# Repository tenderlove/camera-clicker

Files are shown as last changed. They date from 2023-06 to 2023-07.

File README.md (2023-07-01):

# Camera Clicker

This project is a dedicated WiFi client and remote shutter for Olympus OM-D cameras.
It simply connects to the camera, and then you can use the button to fire the camera shutter.
I've only tested this with my OM-D E-M5 Mark III camera, but I believe it will work with any OM-D camera that uses WiFi for its remote shutter application.

<p align="center">
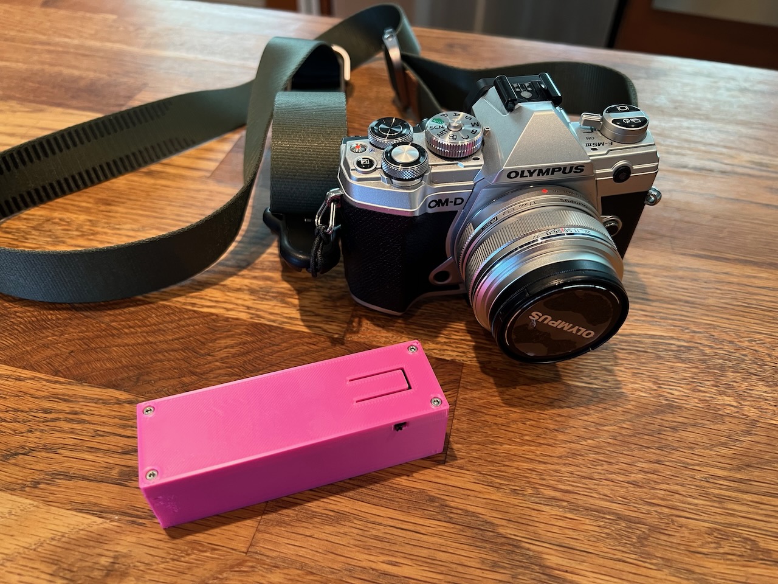
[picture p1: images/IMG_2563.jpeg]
  
</p>

In this repository, you'll find [schematics and PCB designs](pcb), [stl files](housing), and the [firmware](firmware) you need.

## Hardware

The hardware is based around the ESP32.  It uses an [LiFePO4 battery](https://www.digikey.com/en/products/detail/zeus-battery-products/PCIFR18650-1500/9828824) to provide power to the ESP32.
I chose this battery because it provides 3.2v which means I don't need a voltage regulator for the ESP32.
The schematic integrates a recharging circuit, so you can recharge the battery via USB C.

Below are the necessary parts:

| Quantity | Part | Value | Size |
| --- | ---- | ---- | ----- |
| 1 | [Battery Holder](https://www.digikey.com/en/products/detail/keystone-electronics/1042/2745668) |  | BatteryHolder_Keystone_1042_1x18650 |
| 1 | [Battery](https://www.digikey.com/en/products/detail/zeus-battery-products/PCIFR18650-1500/9828824) |  |  |
| 2 | Capacitor | 1uf | 0402 |
| 1 | Capacitor | 22uf | 1206 |
| 1 | Capacitor | 0.1uf | 1206 |
| 2 | LED |  | 1206 |
| 1 | [USB C connector](https://www.digikey.com/en/products/detail/amphenol-cs-fci/10164359-00011LF/18443702) |  | USB_C_Receptacle_Amphenol_10164359-3A |
| 1 | Resistor | 82k | 0402 |
| 1 | Resistor | 3k | 0402 |
| 4 | Resistor | 10k | 1206 |
| 1 | Resistor | 70k | 0402 |
| 1 | Resistor | 2.3k | 0402 |
| 2 | Resistor | 5.1k | 1206 |
| 1 | [Power Switch](https://www.digikey.com/en/products/detail/te-connectivity-alcoswitch-switches/1825232-1/4021554) |  |  |
| 2 | [Programming Switches](https://www.digikey.com/en/products/detail/c-k/PTS526-SK15-SMTR2-LFS/10056626) |  | SW_SPST_PTS526 |
| 1 | [Double Action Switch](https://www.digikey.com/en/products/detail/panasonic-electronic-components/EVP-AXBA1A/4930566) |  | EVPAX-A1A |
| 1 | NTC Thermistor | 10k NTC | 1206 |
| 1 | [Battery Charger](https://www.digikey.com/en/products/detail/texas-instruments/BQ25170DSGR/14124032) | BQ25170 | WSON-8-1EP_2x2mm_P0.5mm_EP0.9x1.6mm |
| 1 | [ESP32](https://www.digikey.com/en/products/detail/espressif-systems/ESP32-MINI-1-N4/13532111) |  |  |

You'll find the gerber files in the [pcb folder](pcb).
Also, I used 10k resistors for the LEDs, but I think it made the LEDs too dim, so maybe 1k is better.
The LEDs are used to indicate charging status, so I don't think they actually matter too much.

Here's a couple photos of the finished PCB:

<p align="center">
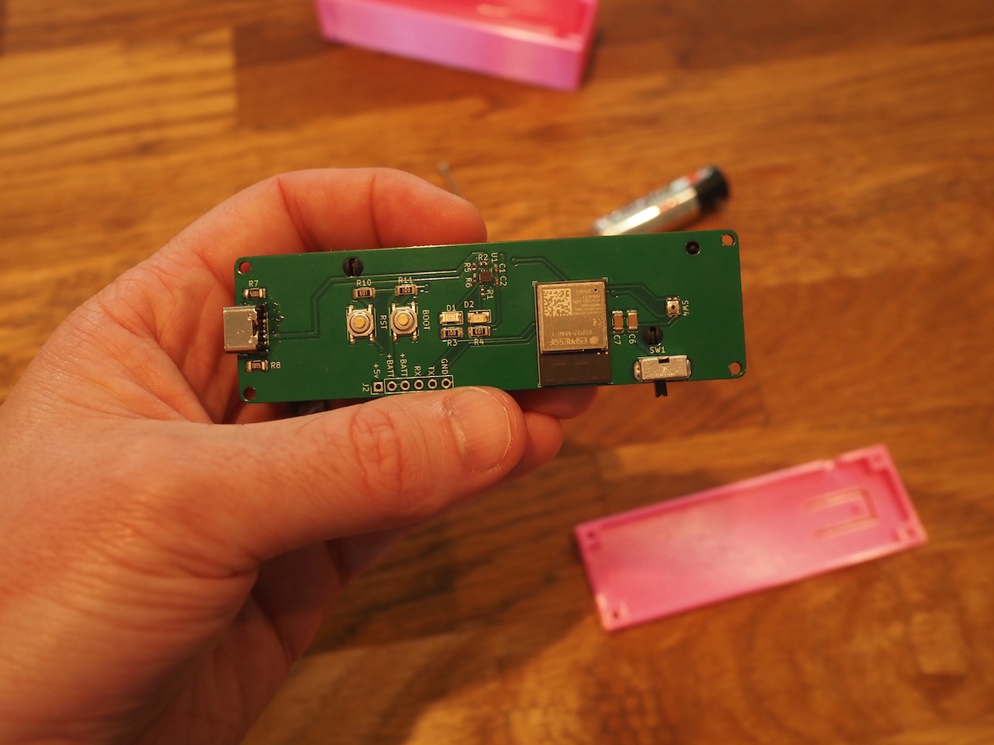
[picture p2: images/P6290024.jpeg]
PCB Top
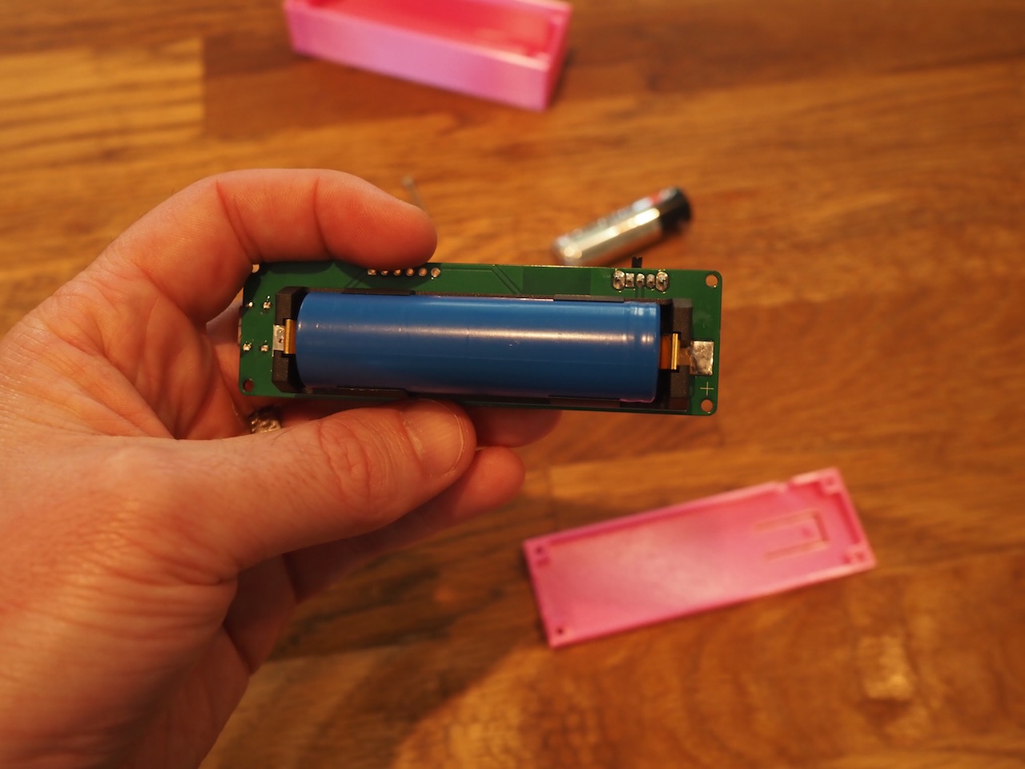
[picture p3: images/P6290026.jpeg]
PCB Bottom
   
</p>

## Firmware

The firmware is in the [firmware](firmware) folder.  It's a standard [ESP IDF](https://github.com/espressif/esp-idf) project.
In order to flash the ESP32, I used a [POGO Pin Clip](https://www.adafruit.com/product/5433) connected to a [USB to Serial](https://www.sparkfun.com/products/12731) board.

Once you have `esp-idf` installed, you can install the firmware like this:

```
$ idf.py build flash
```

Of course, make sure to press the BOOT and RST buttons to put the ESP32 in to programming mode.

## Housing

You can find STL files for the housing in the [housing](housing) folder.
Just print [`top.stl`](housing/top.stl) and [`bottom.stl`](housing/bottom.stl) and the PCB should fit inside.
The housing requires four M2 x 25mm bolts, and four 4mm hex nuts.

The PCB should fit in the housing like this:

<p align="center">
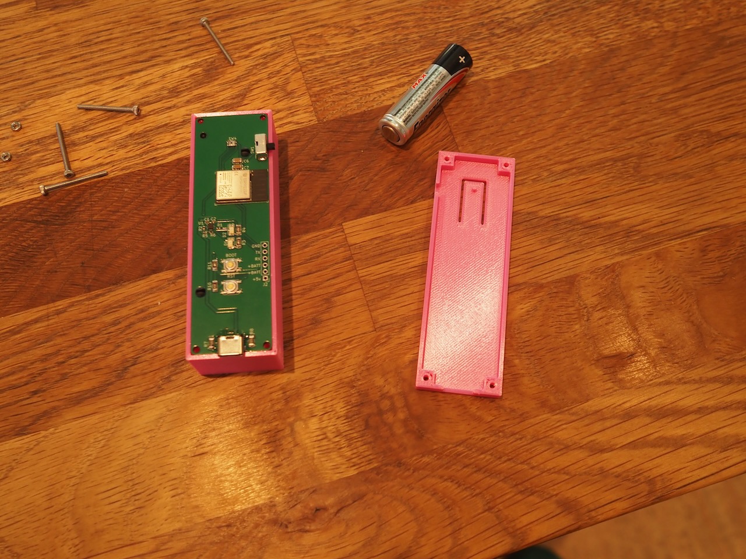
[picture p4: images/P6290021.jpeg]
  
</p>

## Using the Project

When you first turn the clicker on, it will create a WiFi hotspot with the SSID `CameraClicker` and the password `cameraclicker`.

My recommendation is to:

1. Turn on the camera, then enable WiFi client mode
2. Turn on the camera clicker
3. Connect to the camera clicker with your phone
4. Configure the camera clicker with the camera's WiFi settings (they will be displayed on the camera)
5. Use it!

The camera clicker will remember the camera's WiFi connection information, so you only need to configure it once.
If it can't connect to the camera for any reason, it will eventually start the WiFi hotspot again so that you can reconfigure it.

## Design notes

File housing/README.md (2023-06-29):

# Clicker Housing

The clicker housing is made of two parts and uses four M2 x 25mm bolts and four
4mm hex nuts.  Just print `top.stl` and `bottom.stl`.  The PCB should fit
inside!

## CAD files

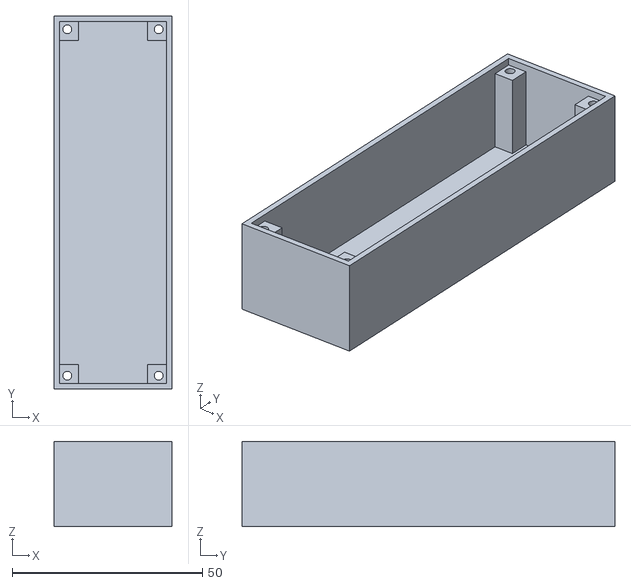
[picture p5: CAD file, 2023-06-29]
housing/bottom.stl
31.0 x 98.0 x 22.4

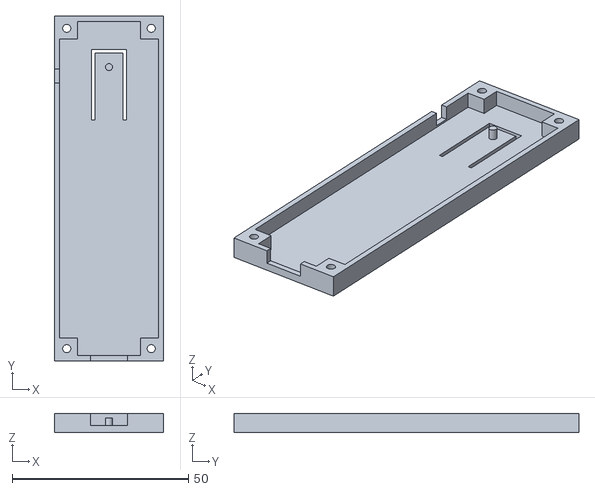
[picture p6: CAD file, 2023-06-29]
housing/top.stl
31.0 x 98.0 x 5.50

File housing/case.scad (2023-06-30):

W = 28;
D = 95;
H = 25;

PCB_W = W;
PCB_D = D;
PCB_H = 1.8;

BATTERY_W = 22;
BATTERY_D = 70;
BATTERY_H = 21 - PCB_H;

PCB_Z = BATTERY_H;

USB_W = 10.5;
USB_D = 5;
USB_H = 3.5;

POWER_SWITCH_W = 5;
POWER_SWITCH_D = 4;
POWER_SWITCH_H = 3.5;

CORNER_D = 5;
CORNER_W = 5;
WALL = 1.5;

PUSH_BUTTON_H = 1.3; // Increase this to make a larger gap above the button
PIN_DIAMETER = 1.1;
BOLT_DIAMETER = 2.3;

BOLT_HEAD_D = 4;
BOLT_HEAD_Z = 2.1;
NUT_D = 4.8;
NUT_Z = 3.1;

MOUNTING_HOLE_X = 24;
MOUNTING_HOLE_Y = 91;

module NegativeSpace() {
  difference() {
    translate([W / 2, D / 2, 0]) {
      translate([0, 0, H / 2])
        difference() {
          cube([W, D, H], center=true);

          // Corner Stands
          color("green")
            for (i = [-1, 1]) {
              for (j = [-1, 1]) {
                w = W - CORNER_W;
                d = D - CORNER_D;
                translate([(i * w / 2), (j * d / 2), 0])
                  cube([CORNER_W, CORNER_D, H + 1], center=true);
              }
            }
        }

      translate([0, 0, PCB_Z + (PCB_H / 2)])
        cube([W, D, PCB_H], center=true);

      // Screw holes
        for (i = [-1, 1]) {
          for (j = [-1, 1]) {
            w = MOUNTING_HOLE_X;
            d = MOUNTING_HOLE_Y;

            translate([(i * w / 2), (j * d / 2), BOLT_HEAD_Z + H - 0.5])
              rotate(180, [1, 0, 0])
              CounterSink(BOLT_HEAD_D, BOLT_HEAD_Z, BOLT_DIAMETER, facets=90);

            translate([(i * w / 2), (j * d / 2), -WALL - 0.1])
            CounterSink(NUT_D, NUT_Z, BOLT_DIAMETER, facets=6);

            translate([(i * w / 2), (j * d / 2), -(WALL + 1)]) {
              color("blue")
                cylinder(H + (WALL * 2) + 2, d = BOLT_DIAMETER, $fn=90);
            }
          }
        }
    }

    translate([PCB_W / 2, D - 13, PCB_Z + PCB_H + PUSH_BUTTON_H])
      cylinder(H - PCB_Z - PCB_H - PUSH_BUTTON_H, d = 2, $fn = 90);
  }

  translate([(PCB_W / 2) - (USB_W / 2), -USB_D, PCB_Z + PCB_H])
    cube([USB_W, USB_D, USB_H]);

  translate([PCB_W, 77.4, PCB_Z + PCB_H])
    cube([POWER_SWITCH_W, POWER_SWITCH_D, POWER_SWITCH_H]);

  // Pin hole
  translate([W / 2, D - 18, H])
    Tab();
    //cylinder(5, d = PIN_DIAMETER, $fn = 90);
}

module Box() {
  difference() {
    w = WALL * 2;
    translate([-WALL, -WALL, -WALL])
      cube([W + w, D + w, H + w]);
    NegativeSpace();
  }
}

module Top() {
  difference() {
    Box();
    whall = WALL + 1;
    w = (whall) * 2;
    translate([-whall, -whall, -whall])
      cube([W + w, D + w, BATTERY_H + whall + PCB_H]);
  }
}

module Bottom() {
  intersection() {
    Box();
    whall = WALL + 1;
    w = (whall) * 2;
    translate([-whall, -whall, -whall])
      cube([W + w, D + w, BATTERY_H + whall + PCB_H - 0.1]);
  }
}

LAYER_HEIGHT = 0.2;

module CounterSink(countersink_d, countersink_z, bolt_d, facets = 6, floating = true) {
  cylinder(countersink_z, d=countersink_d, $fn=facets);

  if (floating) {
    // First bridge
    translate([0, 0, countersink_z + (LAYER_HEIGHT / 2)])
      intersection() {
        color("green")
          cube([bolt_d, countersink_d, LAYER_HEIGHT], center=true);
      }

    color("blue")
    // Second bridge
    translate([0, 0, countersink_z + (LAYER_HEIGHT / 2) + LAYER_HEIGHT])
      cube([bolt_d, bolt_d, LAYER_HEIGHT], center=true);
  }
}

module Tab() {
  TAB_X = 10;
  TAB_Y = 20;
  TAB_Z = WALL + 0.2;
  TAB_GAP = 1;
  translate([-TAB_X / 2, -TAB_Y / 2, -0.1])
  difference() {
    cube([TAB_X, TAB_Y, TAB_Z]);
    translate([TAB_GAP, -0.1, -0.1])
    cube([TAB_X - (TAB_GAP * 2), TAB_Y - (TAB_GAP - 0.1), TAB_Z + 0.2]);
  }
}

rendering = "full";

if (rendering == "top") {
  rotate(180, [0, 1, 0])
    Top();
}

if (rendering == "bottom") {
  Bottom();
}

if (rendering == "full") {
  Bottom();
  rotate(180, [0, 1, 0])
    Top();
}

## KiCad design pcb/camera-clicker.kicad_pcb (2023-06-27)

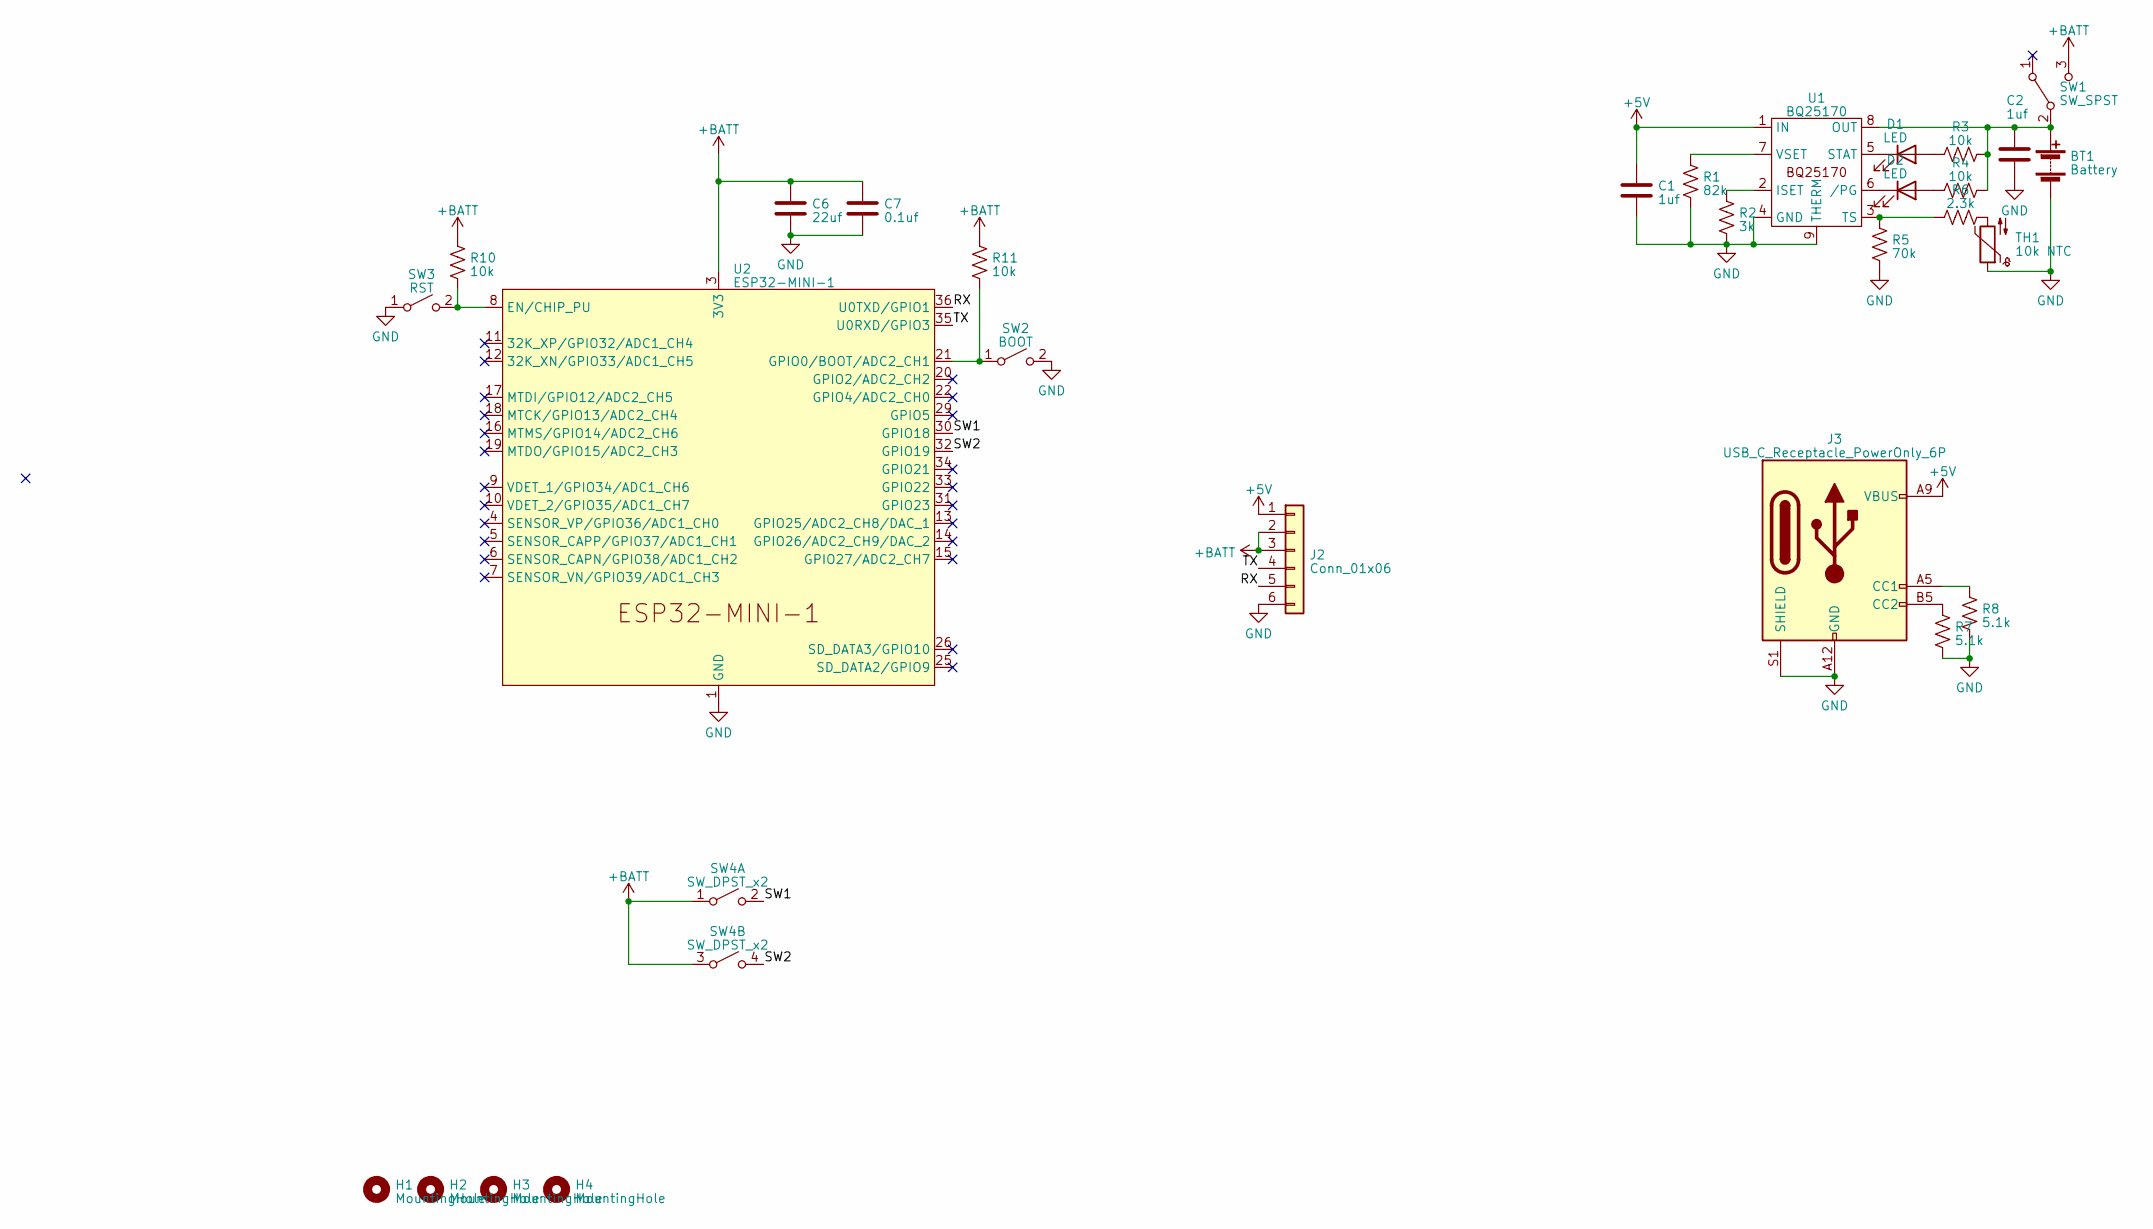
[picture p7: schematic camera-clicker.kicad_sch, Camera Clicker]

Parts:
BT1: Battery; BatteryHolder_Keystone_1042_1x18650
C1, C2: 1uf; C_0402_1005Metric
C6: 22uf; C_1206_3216Metric
C7: 0.1uf; C_1206_3216Metric
D1, D2: LED; LED_1206_3216Metric
H1, H2, H3, H4: MountingHole; MountingHole_2.2mm_M2
J2: Conn_01x06; PinHeader_1x06_P2.54mm_Vertical
J3: USB_C_Receptacle_PowerOnly_6P; USB_C_Receptacle_Amphenol_10164359-3A
R1: 82k; R_0402_1005Metric
R2: 3k; R_0402_1005Metric
R3, R4, R10, R11: 10k; R_1206_3216Metric
R5: 70k; R_0402_1005Metric
R6: 2.3k; R_0402_1005Metric
R7, R8: 5.1k; R_1206_3216Metric
SW1: SW_SPST; SW_CuK_OS102011MA1QN1_SPDT_Angled
SW2: BOOT; SW_SPST_PTS526
SW3: RST; SW_SPST_PTS526
SW4: SW_DPST_x2; EVPAX-A1A
TH1: 10k NTC; R_1206_3216Metric_Pad1.30x1.75mm_HandSolder
U1: BQ25170; WSON-8-1EP_2x2mm_P0.5mm_EP0.9x1.6mm
U2: ESP32-MINI-1

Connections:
+5V: C1.1, J2.1, J3.A9 (VBUS), J3.B9 (VBUS), U1.1 (IN)
+BATT: C6.1, C7.1, J2.2, J2.3, R10.1, R11.1, SW1.3 (C), SW4.1 (A), SW4.3 (A), U2.3 (3V3)
/RX: J2.5, U2.36 (U0TXD/GPIO1)
/SW1: SW4.2 (B), U2.30 (GPIO18)
/SW2: SW4.4 (B), U2.32 (GPIO19)
/TX: J2.4, U2.35 (U0RXD/GPIO3)
GND: BT1.2 (-), C1.2, C2.2, C6.2, C7.2, J2.6, J3.A12 (GND), J3.B12 (GND), J3.S1 (SHIELD), R1.2, R2.2, R5.2, R7.2, R8.2, SW2.2 (B), SW3.1 (A), TH1.1, U1.4 (GND), U1.9 (THERM), U2.1 (GND), U2.2 (GND), U2.27 (GND), U2.38 (GND), U2.39 (GND), U2.40 (GND), U2.41 (GND), U2.42 (GND), U2.43 (GND), U2.44 (GND), U2.45 (GND), U2.46 (GND), U2.47 (GND), U2.48 (GND), U2.49 (GND), U2.50 (GND), U2.51 (GND), U2.52 (GND), U2.53 (GND), U2.54 (GND), U2.55 (GND)
unnamed: BT1.1 (+), C2.1, R3.2, R4.2, SW1.2 (B), U1.8 (OUT)
unnamed: D1.2 (A), R3.1
unnamed: D1.1 (K), U1.5 (STAT)
unnamed: D2.2 (A), R4.1
unnamed: D2.1 (K), U1.6 (/PG)
unnamed: J3.A5 (CC1), R8.1
unnamed: J3.B5 (CC2), R7.1
unnamed: R6.2, TH1.2
unnamed: R11.2, SW2.1 (A), U2.21 (GPIO0/BOOT/ADC2_CH1)
unnamed: R10.2, SW3.2 (B), U2.8 (EN/CHIP_PU)
unnamed: R2.1, U1.2 (ISET)
unnamed: R5.1, R6.1, U1.3 (TS)
unnamed: R1.1, U1.7 (VSET)

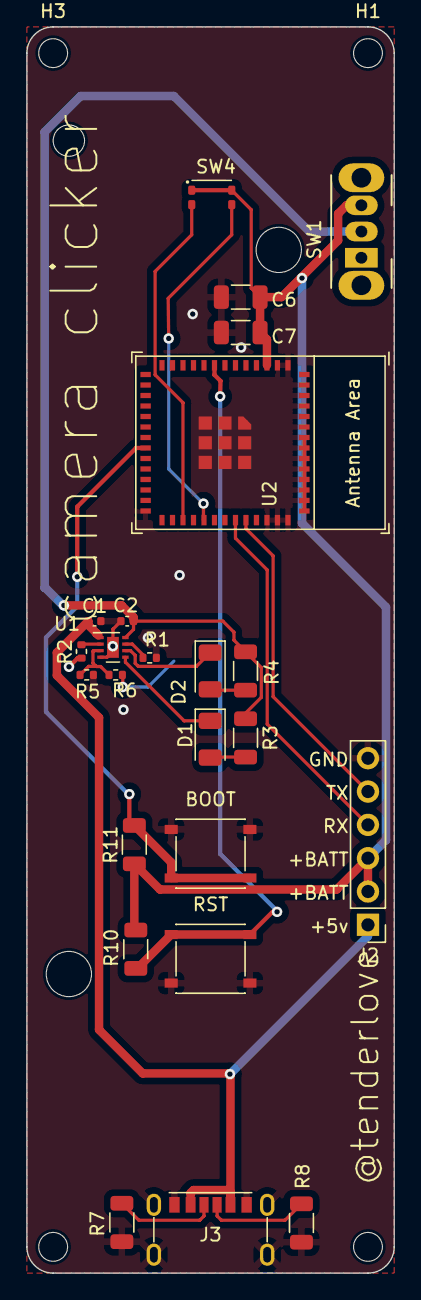
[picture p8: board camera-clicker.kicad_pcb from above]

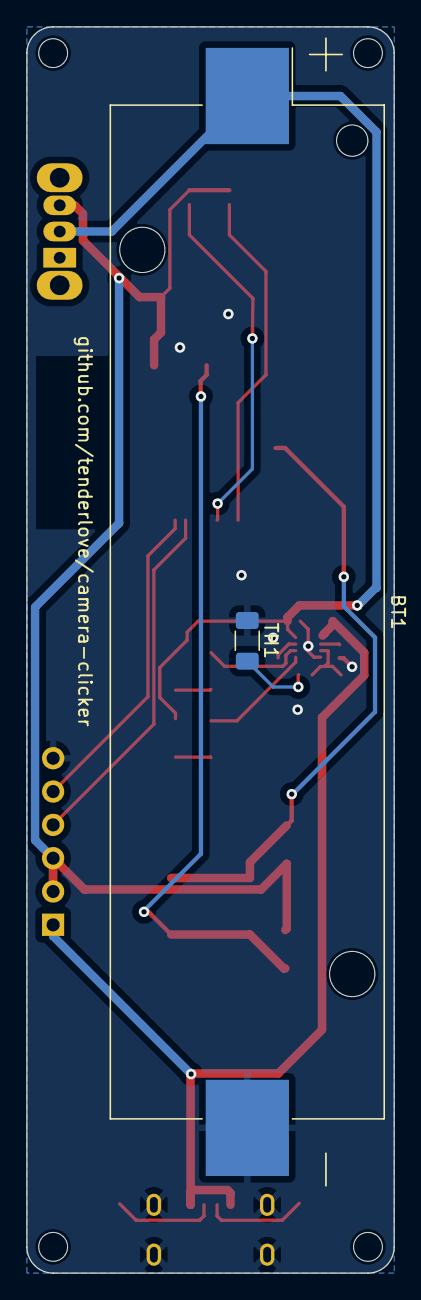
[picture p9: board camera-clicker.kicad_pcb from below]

Board: 2 copper layers, 28.0 x 95.0 mm, 30 parts (2 on the bottom side), 20 nets.

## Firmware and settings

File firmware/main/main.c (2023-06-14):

#include <stdio.h>
#include <inttypes.h>
#include "sdkconfig.h"
#include <esp_wifi.h>
#include <esp_netif.h>
#include <freertos/FreeRTOS.h>
#include <freertos/task.h>
#include <esp_system.h>
#include <esp_log.h>
#include <lwip/ip4_addr.h>
#include "esp_chip_info.h"
#include "esp_flash.h"
#include "wifi_manager.h"
#include <esp_http_client.h>
#include <driver/gpio.h>

/* @brief tag used for ESP serial console messages */
static const char TAG[] = "main";

#define MAX_HTTP_RECV_BUFFER 512
#define MAX_HTTP_OUTPUT_BUFFER 2048
#define ESP_INTR_FLAG_DEFAULT 0

#define GPIO_INPUT_IO_0     18
#define GPIO_INPUT_IO_1     19
#define GPIO_INPUT_PIN_SEL  ((1ULL<<GPIO_INPUT_IO_0) | (1ULL<<GPIO_INPUT_IO_1))

static QueueHandle_t tx_task_queue;

esp_err_t _http_event_handler(esp_http_client_event_t *evt)
{
    return ESP_OK;
}

uint8_t mask0 = 0;
uint8_t mask1 = 0;
int io0 = 0;
int io1 = 0;

/**
 * @brief this is an exemple of a callback that you can setup in your own app to get notified of wifi manager event.
 */
void cb_connection_ok(void *pvParameter){
    ip_event_got_ip_t* param = (ip_event_got_ip_t*)pvParameter;

    /* transform IP to human readable string */
    char str_ip[16];
    esp_ip4addr_ntoa(&param->ip_info.ip, str_ip, IP4ADDR_STRLEN_MAX);

    ESP_LOGI(TAG, "I have a connection and my IP is %s!", str_ip);

    unsigned int tx_action = 1;
    xQueueSend(tx_task_queue, &tx_action, portMAX_DELAY);
}

void monitoring_task(void *pvParameter)
{
    for(;;){
        ESP_LOGI(TAG, "free heap: %"PRIu32, esp_get_free_heap_size());
        vTaskDelay( pdMS_TO_TICKS(10000) );
    }
}

void button_task(void *pvParameter)
{
    for(;;){
        uint8_t current0 = gpio_get_level(GPIO_INPUT_IO_0);
        uint8_t current1 = gpio_get_level(GPIO_INPUT_IO_1);

        mask0 = (mask0 << 1) | current0 | 0xF0;
        mask1 = (mask1 << 1) | current1 | 0xF0;

        // It's been high or low for 4 bits (4 * 5ms == 20ms)
        if (mask0 == 0xF0 || mask0 == 0xFF) {
            if (current0 != io0) {
                io0 = current0;
                unsigned int tx_action = GPIO_INPUT_IO_0;
                xQueueSend(tx_task_queue, &tx_action, portMAX_DELAY);
            }
        }

        if (mask1 == 0xF0 || mask1 == 0xFF) {
            if (current1 != io1) {
                io1 = current1;
                unsigned int tx_action = GPIO_INPUT_IO_1;
                xQueueSend(tx_task_queue, &tx_action, portMAX_DELAY);
            }
        }
        vTaskDelay( pdMS_TO_TICKS(10) );
    }
}

static inline esp_err_t make_request(char * path, char * action)
{
    char local_response_buffer[MAX_HTTP_OUTPUT_BUFFER] = {0};

    esp_http_client_config_t config = {
        .host = "192.168.0.10",
        .path = path,
        .query = action,
        .event_handler = _http_event_handler,
        .user_data = local_response_buffer,        // Pass address of local buffer to get response
        .disable_auto_redirect = true,
    };

    esp_http_client_handle_t client = esp_http_client_init(&config);

    // GET
    esp_err_t err = esp_http_client_perform(client);
    if (err == ESP_OK) {
        ESP_LOGI(TAG, "HTTP GET Status = %d, content_length = %"PRIu64,
                esp_http_client_get_status_code(client),
                esp_http_client_get_content_length(client));
    } else {
        ESP_LOGE(TAG, "HTTP GET request failed: %s", esp_err_to_name(err));
    }
    esp_http_client_cleanup(client);

    return err;
}

static inline esp_err_t cam_button(char * action)
{
    return make_request("/exec_shutter.cgi", action);
}

void
transmit_task(void *arg)
{
    while (1) {
        unsigned int action;
        xQueueReceive(tx_task_queue, &action, portMAX_DELAY);

        printf("transmitting %d\n", action);

        switch(action) {
            case 1:
                make_request("/switch_cammode.cgi", "mode=shutter");

                break;
            case GPIO_INPUT_IO_0:
                if (gpio_get_level(GPIO_INPUT_IO_0)) {
                    printf("button 1 pressed\n");
                    cam_button("com=1stpush");
                } else {
                    printf("button 1 released\n");
                    cam_button("com=1strelease");
                }
                break;
            case GPIO_INPUT_IO_1:
                if (gpio_get_level(GPIO_INPUT_IO_1)) {
                    printf("button 2 pressed\n");
                    cam_button("com=2ndpush");
                } else {
                    printf("button 2 released\n");
                    cam_button("com=2ndrelease");
                }
                break;
        }
    }
}

void app_main(void)
{
    tx_task_queue = xQueueCreate(5, sizeof(uint32_t));
    xTaskCreatePinnedToCore(transmit_task, "request task", 4096, NULL, 8, NULL, tskNO_AFFINITY);

    gpio_config_t io_conf = {};
    io_conf.intr_type = GPIO_INTR_ANYEDGE;
    io_conf.pin_bit_mask = GPIO_INPUT_PIN_SEL;
    io_conf.mode = GPIO_MODE_INPUT;
    io_conf.pull_down_en = 1;
    gpio_config(&io_conf);

    io0 = gpio_get_level(GPIO_INPUT_IO_0);
    io1 = gpio_get_level(GPIO_INPUT_IO_1);
    if (io0) {
        mask0 = 0xFF;
    }
    else {
        mask0 = 0xF0;
    }

    if (io1) {
        mask1 = 0xFF;
    }
    else {
        mask1 = 0xF0;
    }

    /* start the wifi manager */
    wifi_manager_start();

    wifi_manager_set_callback(WM_EVENT_STA_GOT_IP, &cb_connection_ok);
    xTaskCreatePinnedToCore(monitoring_task, "monitoring_task", 2048, NULL, 1, NULL, tskNO_AFFINITY);
    xTaskCreatePinnedToCore(button_task, "button_task", 4096, NULL, 9, NULL, tskNO_AFFINITY);
}

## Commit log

2023-05-23 switching camera mode on connect
2023-05-23 buttons are working
2023-05-24 adding initial pcb stuff
    [camera-clicker.kicad_pcb, camera-clicker.kicad_sch]
2023-05-25 updating design
    [camera-clicker.kicad_sch]
2023-05-31 first layout
    [camera-clicker.kicad_pcb, camera-clicker.kicad_sch]
2023-05-31 fixing position
    [camera-clicker.kicad_pcb]
2023-05-31 more pcb
    [camera-clicker.kicad_pcb, camera-clicker.kicad_sch]
2023-06-13 update pcb
    [camera-clicker-B_Cu.gbr, camera-clicker-B_Mask.gbr, camera-clicker-B_Paste.gbr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]
2023-06-13 button is working
2023-06-14 refactor button presses
2023-06-14 add new switch footprint
2023-06-17 adding footprint for USB C receptacle
2023-06-17 new pcb design
    [camera-clicker.kicad_pcb, camera-clicker.kicad_sch]
2023-06-27 updating pcb
    [camera-clicker-B_Cu.gbr, camera-clicker-B_Mask.gbr, camera-clicker-B_Paste.gbr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]
2023-06-27 initial case
    [case.scad]
2023-06-28 adding counter sunk holes, and bolt head holes
    [case.scad]
2023-06-28 testing pushbutton and nut height
    [case.scad]
2023-06-29 2.1 was too small
    [case.scad]
2023-06-29 add a button
    [case.scad]
2023-06-29 Use a tab for the switch button
    [bottom.stl, case.scad, top.stl]
2023-06-30 pull tab gap in to a variable
    [case.scad]

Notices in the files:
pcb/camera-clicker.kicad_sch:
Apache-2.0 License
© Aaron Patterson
